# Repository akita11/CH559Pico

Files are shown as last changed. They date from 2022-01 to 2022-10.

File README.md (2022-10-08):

# CH559Pico

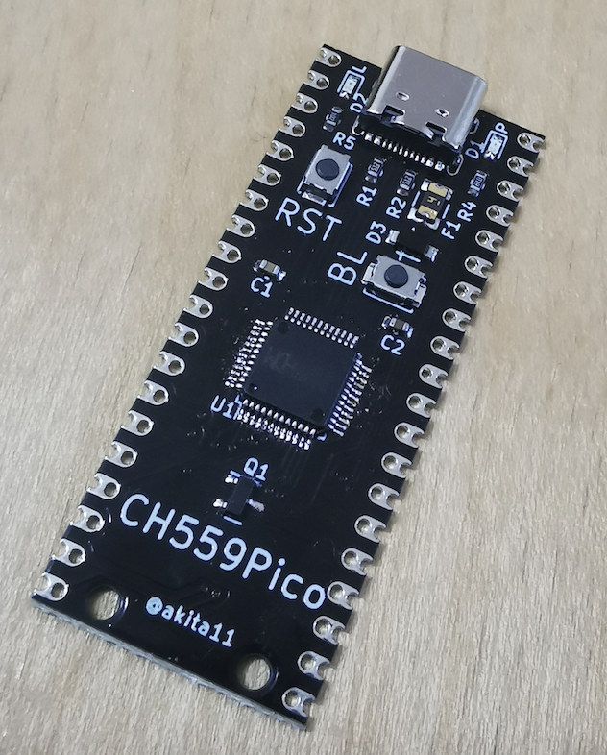
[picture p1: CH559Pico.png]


[WCH(南京沁恒微电子股份有限公司)](http://wch-ic.com/)の8ビットマイコン[CH559](http://wch-ic.com/products/CH559.html)を使った、RaspberryPi Pico型のマイコンボードです。
主な特徴は以下のとおりです。

- RaspberryPi Pico型
- [ArduinoIDEなどでプログラム開発が可能](https://qiita.com/akita11/items/d7baed4ca3c06e292637)
- USBペリフェラル（キーボードやUSBメモリなど）、USBホストとして動作可能

またRaspberryPi Picoとは、以下のような違いがあります。
- 一部ピンの機能が異なる
- IOピンは基本3.3V（P1.0-7とP4.6/7のみ5V入力OK）
- +3.3V出力の電流供給能力は100mA程度（CH552内蔵レギュレータの性能）
- リセット(RST)は正論理で、"1"でリセット
- +5V端子に、外部電源から+5Vを供給可能（内部にレギュレータはないので、+5Vを超える電圧は不可）

## ピン配置

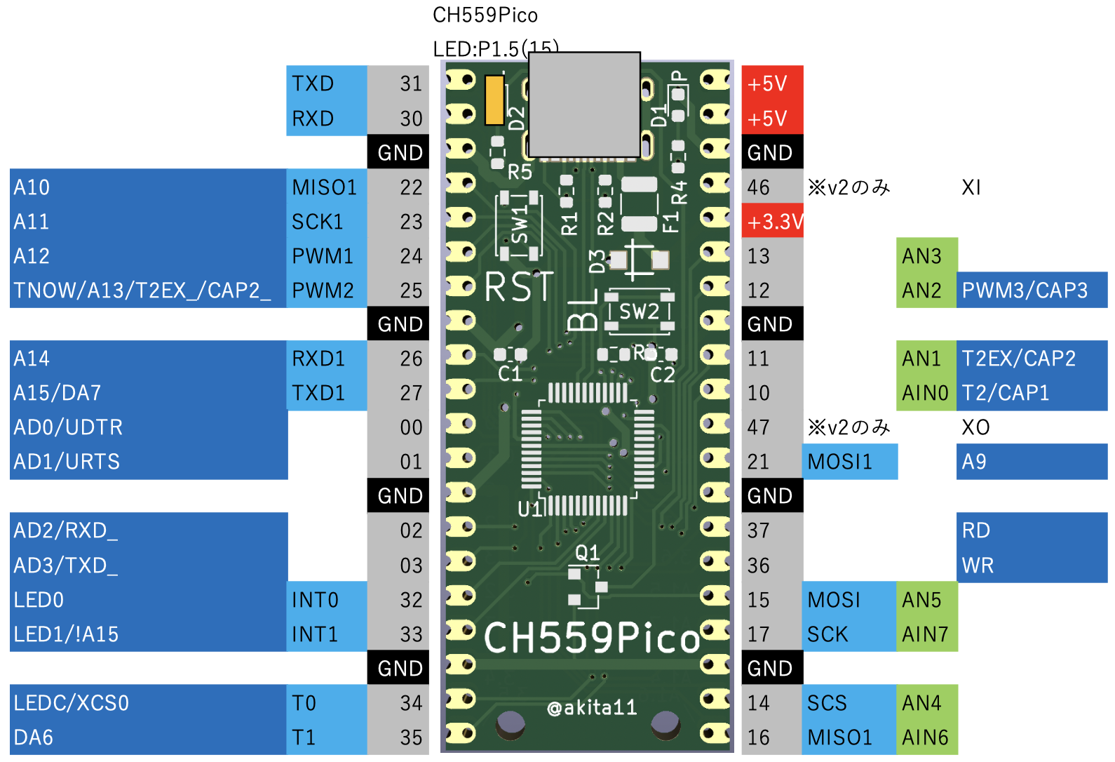
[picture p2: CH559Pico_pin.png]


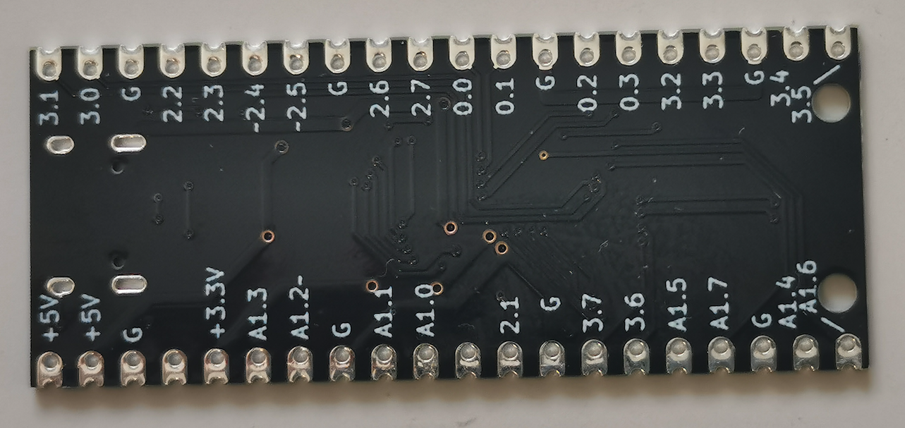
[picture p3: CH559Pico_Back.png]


基板上の"LED"（オレンジ）はP1.5で駆動できます。

※v2ではP4.6とP4.7が空きピンに接続され、水晶発振子を接続できます（裏面に表面実装水晶振動子の接続パッドもあり）

# 訂正

基板上の2個のシルク表示が逆になっているロットがあります。正しくは、RSTスイッチ側のD2が"LED"（オレンジ）、反対側のD1が"POW"（緑、電源インジケータ）です。

## Author

Junichi Akita (@akita11) / akita@ifdl.jp

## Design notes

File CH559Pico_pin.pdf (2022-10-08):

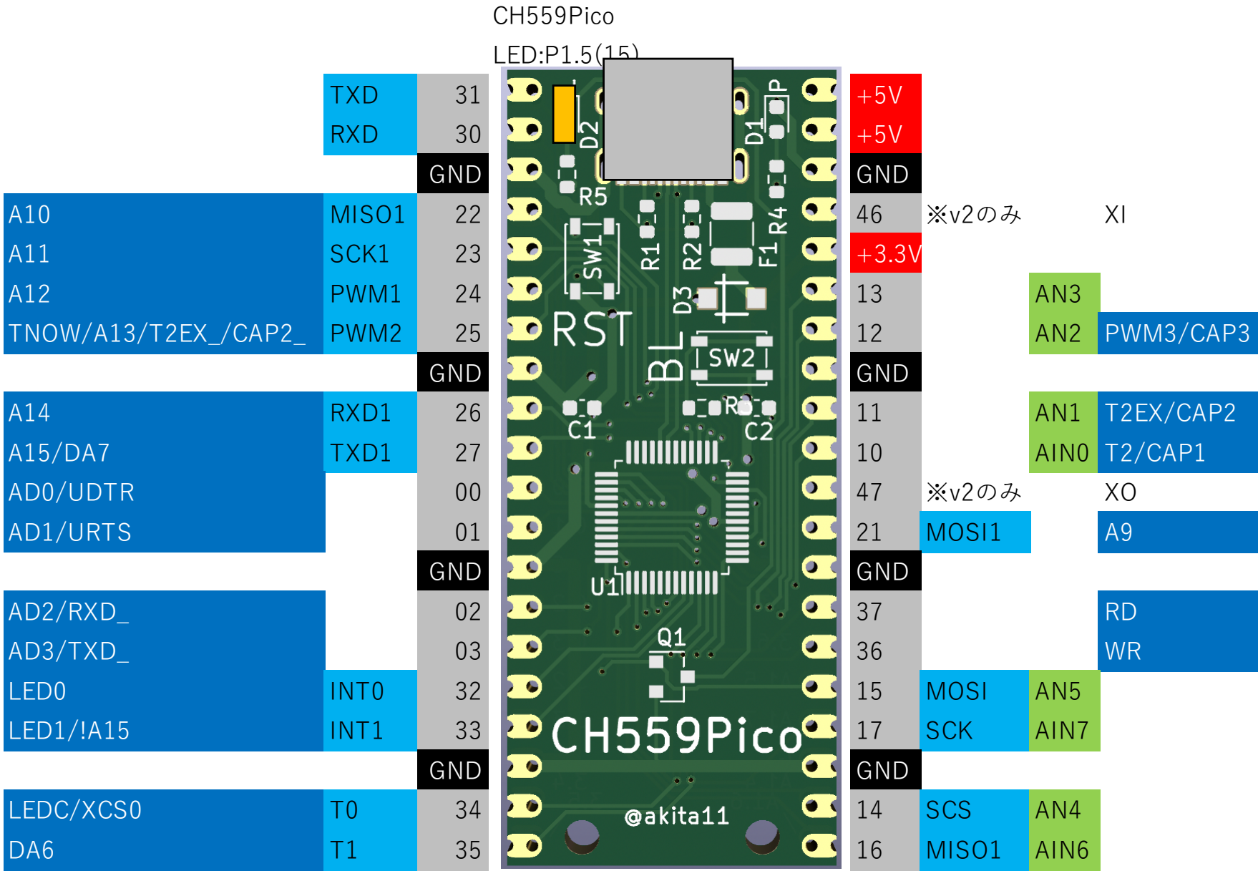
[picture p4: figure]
CH559Pico; LED:P1.5(15); TXD; RXD; GND; MISO1; SCK1; PWM1; TNOW/A13/T2EX_/CAP2_; PWM2; PWM3/CAP3; RXD1; T2EX/CAP2; TXD1; AIN0; T2/CAP1; AD0/UDTR; AD1/URTS; MOSI1; AD2/RXD_; AD3/TXD_; LED0; INT0; MOSI; LED1/!A15; INT1; SCK; AIN7; LEDC/XCS0; SCS; AIN6

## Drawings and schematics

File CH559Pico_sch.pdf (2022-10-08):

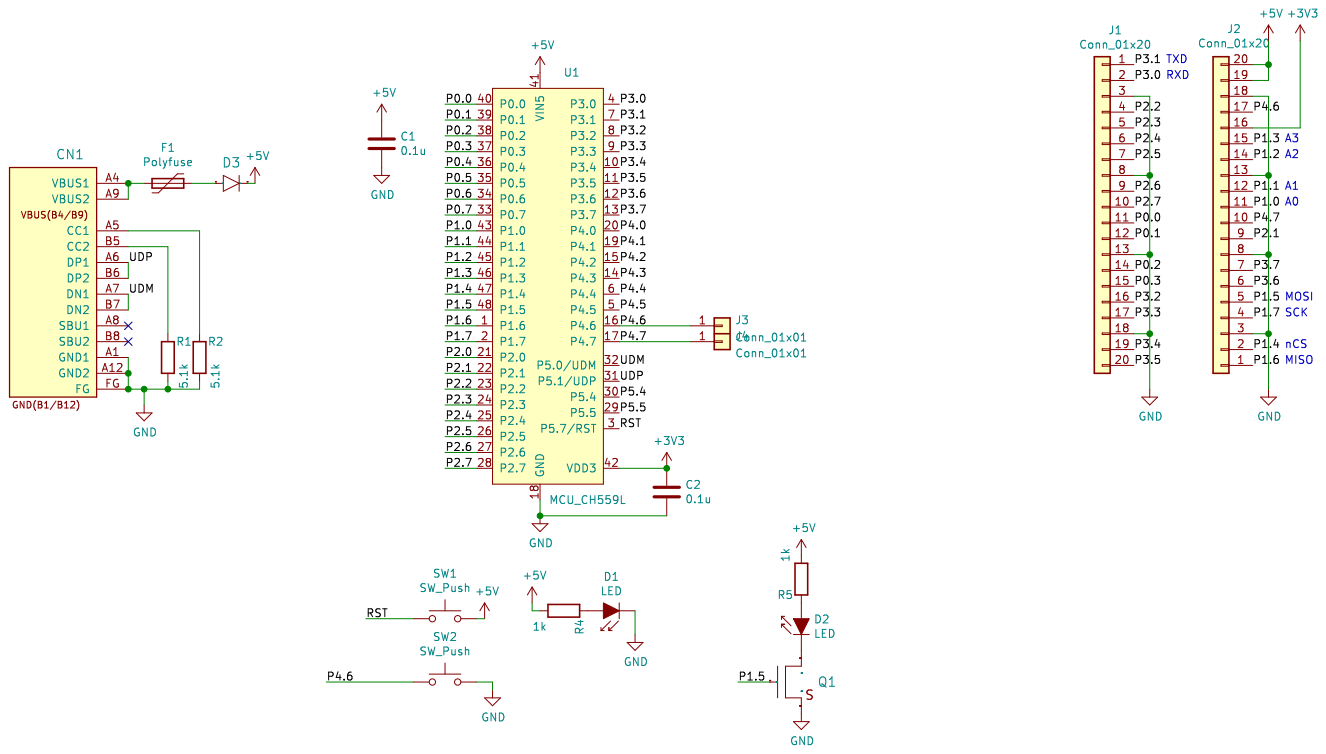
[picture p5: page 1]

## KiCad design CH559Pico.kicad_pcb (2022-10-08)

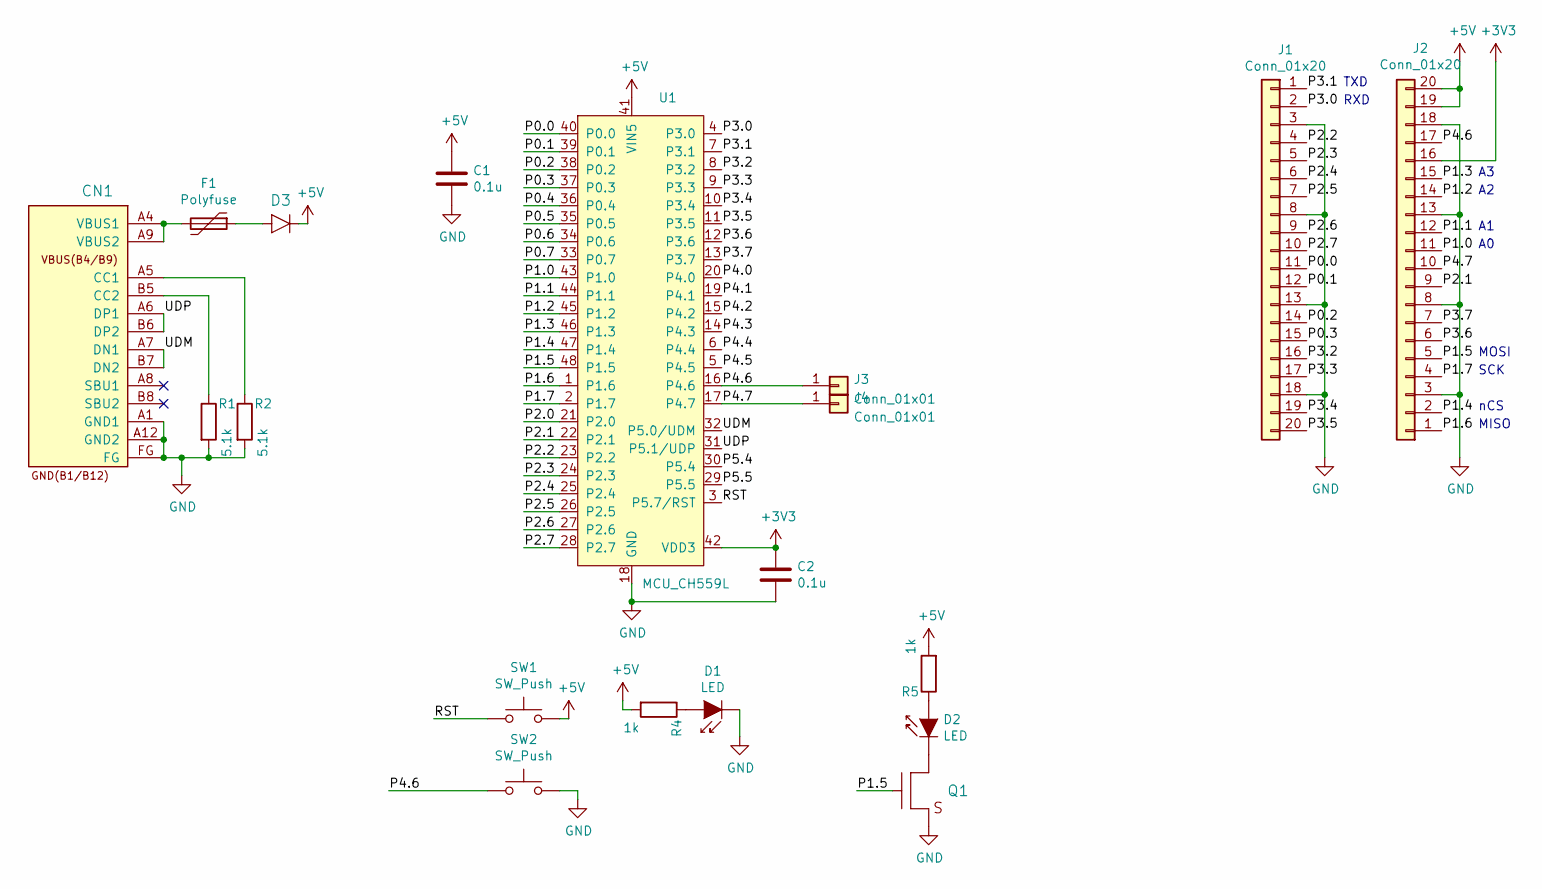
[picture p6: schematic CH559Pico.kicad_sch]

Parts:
C1, C2: 0.1u; C_0603_1608Metric; LCSC C14663
CN1: CON_USB-C-16; USB-C_16P_TH; LCSC C165948
D1: LED; LED_0603_1608Metric; LCSC C165982
D2: LED; LED_0603_1608Metric; LCSC C138546
D3: DIODE; D_SOD123FL; LCSC C190475
F1: Polyfuse; R_1210_3225Metric; LCSC C2982267
J1, J2: Conn_01x20; Socker2.54mm_20p_OvalPad
J3, J4: Conn_01x01; Pad_SMD1.6mm
Q1: TR_NMOS_IRLML6344; SOT-23; LCSC C20917
R1, R2: 5.1k; R_0603_1608Metric; LCSC C23186
R4, R5: 1k; R_0603_1608Metric; LCSC C21190
SW1, SW2: SW_Push; SW_Push_SPST_NO_Alps_SKRK; LCSC C2837082
U1: MCU_CH559L; LQFP-48_7x7mm_P0.5mm; LCSC C150548

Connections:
+3V3: C2.1, J2.16, U1.42 (VDD3)
+5V: C1.1, D3.K, J2.19, J2.20, R4.2, R5.2, SW1.2, U1.41 (VIN5)
/P0.0: J1.11, U1.40 (P0.0)
/P0.1: J1.12, U1.39 (P0.1)
/P0.2: J1.14, U1.38 (P0.2)
/P0.3: J1.15, U1.37 (P0.3)
/P0.4: U1.36 (P0.4)
/P0.5: U1.35 (P0.5)
/P0.6: U1.34 (P0.6)
/P0.7: U1.33 (P0.7)
/P1.0: J2.11, U1.43 (P1.0)
/P1.1: J2.12, U1.44 (P1.1)
/P1.2: J2.14, U1.45 (P1.2)
/P1.3: J2.15, U1.46 (P1.3)
/P1.4: J2.2, U1.47 (P1.4)
/P1.5: J2.5, Q1.1 (G), U1.48 (P1.5)
/P1.6: J2.1, U1.1 (P1.6)
/P1.7: J2.4, U1.2 (P1.7)
/P2.0: U1.21 (P2.0)
/P2.1: J2.9, U1.22 (P2.1)
/P2.2: J1.4, U1.23 (P2.2)
/P2.3: J1.5, U1.24 (P2.3)
/P2.4: J1.6, U1.25 (P2.4)
/P2.5: J1.7, U1.26 (P2.5)
/P2.6: J1.9, U1.27 (P2.6)
/P2.7: J1.10, U1.28 (P2.7)
/P3.0: J1.2, U1.4 (P3.0)
/P3.1: J1.1, U1.7 (P3.1)
/P3.2: J1.16, U1.8 (P3.2)
/P3.3: J1.17, U1.9 (P3.3)
/P3.4: J1.19, U1.10 (P3.4)
/P3.5: J1.20, U1.11 (P3.5)
/P3.6: J2.6, U1.12 (P3.6)
/P3.7: J2.7, U1.13 (P3.7)
/P4.0: U1.20 (P4.0)
/P4.1: U1.19 (P4.1)
/P4.2: U1.15 (P4.2)
/P4.3: U1.14 (P4.3)
/P4.4: U1.6 (P4.4)
/P4.5: U1.5 (P4.5)
/P4.6: J2.17, J3.1, SW2.1, U1.16 (P4.6)
/P4.7: J2.10, J4.1, U1.17 (P4.7)
/P5.4: U1.30 (P5.4)
/P5.5: U1.29 (P5.5)
/RST: SW1.1, U1.3 (P5.7/RST)
/UDM: CN1.A7 (DN1), CN1.B7 (DN2), U1.32 (P5.0/UDM)
/UDP: CN1.A6 (DP1), CN1.B6 (DP2), U1.31 (P5.1/UDP)
GND: C1.2, C2.2, CN1.A1 (GND1), CN1.A12 (GND2), CN1.FG, D1.1 (K), J1.3, J1.8, J1.13, J1.18, J2.3, J2.8, J2.13, J2.18, Q1.2 (S), R1.2, R2.2, SW2.2, U1.18 (GND)
unnamed: CN1.A4 (VBUS1), CN1.A9 (VBUS2), F1.2
unnamed: CN1.A5 (CC1), R2.1
unnamed: CN1.B5 (CC2), R1.1
unnamed: D1.2 (A), R4.1
unnamed: D2.1 (K), Q1.3 (D)
unnamed: D2.2 (A), R5.1
unnamed: D3.A, F1.1

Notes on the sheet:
RXD
SCK
MOSI
nCS
MISO
TXD

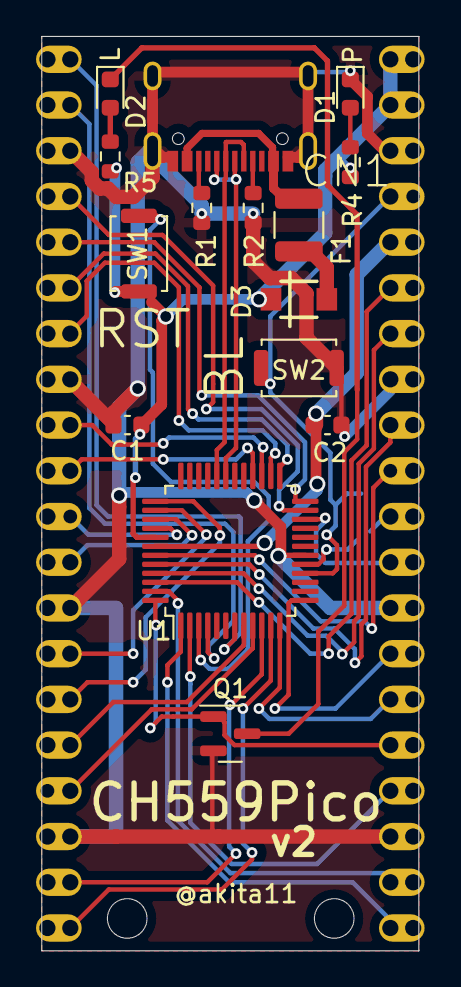
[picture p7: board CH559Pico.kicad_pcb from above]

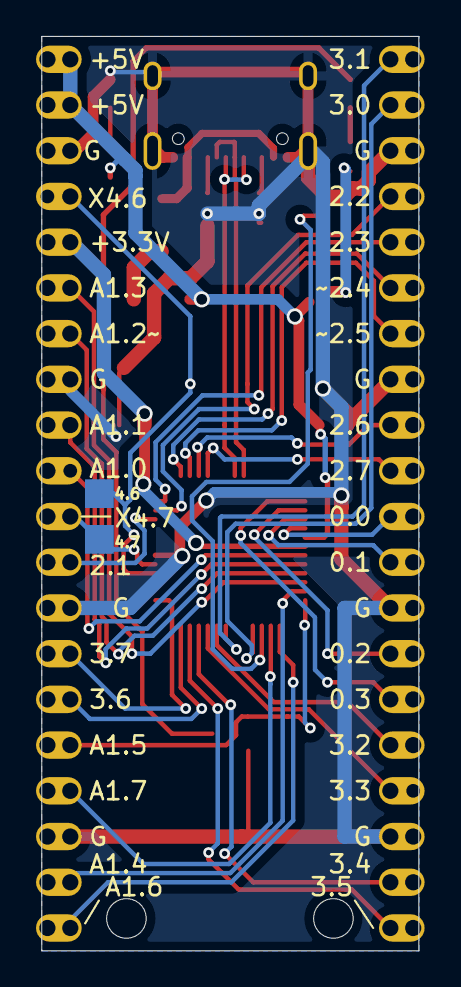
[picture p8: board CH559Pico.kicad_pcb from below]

Board: 2 copper layers, 21.0 x 50.8 mm, 19 parts (2 on the bottom side), 42 nets.

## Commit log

2022-01-19 BLピン・シルクの修正
    [CH558Pico.kicad_pcb, CH558Pico.kicad_sch]
2022-01-19 add pin map
    [CH558Pico.sch, CH559Pico_pin.xlsx]
2022-01-20 rename pin map files
    [CH558Pico_pin.xlsx]
2022-01-20 pin map image resize
2022-01-20 外部電源について追記
2022-01-20 rename to CH559Pico
    [CH559Pico.kicad_pcb, CH559Pico.kicad_sch, CH559Pico_pin.xlsx]
2022-01-26 modify pin map
    [CH559Pico_pin.xlsx]
2022-01-28 +3.3V出力電流について追記
2022-01-28 add schematic
2022-10-08 update for v2
    [CH559Pico.kicad_pcb, CH559Pico.kicad_sch, CH559Pico_pin.xlsx]
